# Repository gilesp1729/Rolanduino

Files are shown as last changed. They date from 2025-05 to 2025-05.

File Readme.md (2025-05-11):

# Rolanduino – An Arduino piano/synthesizer

There are quite a few old Roland digital pianos lying around, but parts are impossible to obtain. I had an old HP-237Re whose mechanics were OK but the logic board had died. This project combines the scanning of the keyboard with a synthesizer based on a fork of [Arduino-midi-sound-module](https://github.com/DLehenbauer/arduino-midi-sound-module). I wondered if a Mega2560 could both scan the keyboard and manage the sound production seamlessly…

## Scanning the keyboard

There are many models of these old keyboards but the scanning details are usually quite similar. The schematics of a similar (but not quite the same!) model of Roland are provided here.

The keyboard is wired in groups of 8 keys (11 groups = 88 keys in total) The 8 T-lines are normally high, but each is pulled low in turn to sense each of the 8 notes in each group. Each group has a half-press and full-press line, the timing between them is used to sense key velocity.

In the service manuals they are called SM and PM lines (I don't know what this stands for) but some older keyboards have break and make lines instead.

So there are 11 groups \* 2 bits = 22 bits = 3 bytes reported back from each scan, for a total of 24 bytes from 8 scans.

The PM/SM lines are wired as follows on the Mega to the ports on the heel of the board (the double row connector) while the T lines are connected to port F. There are a lot of wires!

```
  bit     7       6       5       4       3       2       1       0
        -----------------------------------------------------------------
  PORTL |  PM3  |  SM3  |  PM2  |  SM2  |  PM1  |  SM1  |  PM0  |  SM0  |
        -----------------------------------------------------------------
        -----------------------------------------------------------------
  PORTC |  PM7  |  SM7  |  PM6  |  SM6  |  PM5  |  SM5  |  PM4  |  SM4  |
        -----------------------------------------------------------------
        -----------------------------------------------------------------
  PORTA |       |       | PM10  | SM10  |  PM9  |  SM9  |  PM8  |  SM8  |
        -----------------------------------------------------------------
        -----------------------------------------------------------------
  PORTF |  T7   |  T6   |  T5   |  T4   |  T3   |  T2   |  T1   |  T0   |
(output)-----------------------------------------------------------------
```

## Wiring it up

The old logic board is connected to the keyboard by a couple of flat flexible (FFC) cables. These are fragile and unobtainable, as are their sockets. Fortunately the logic board has holes for a couple of different types of keyboards which could be used for 0.1” pitch pins. I sawed the rest of the logic board off to retain the FFC sockets.

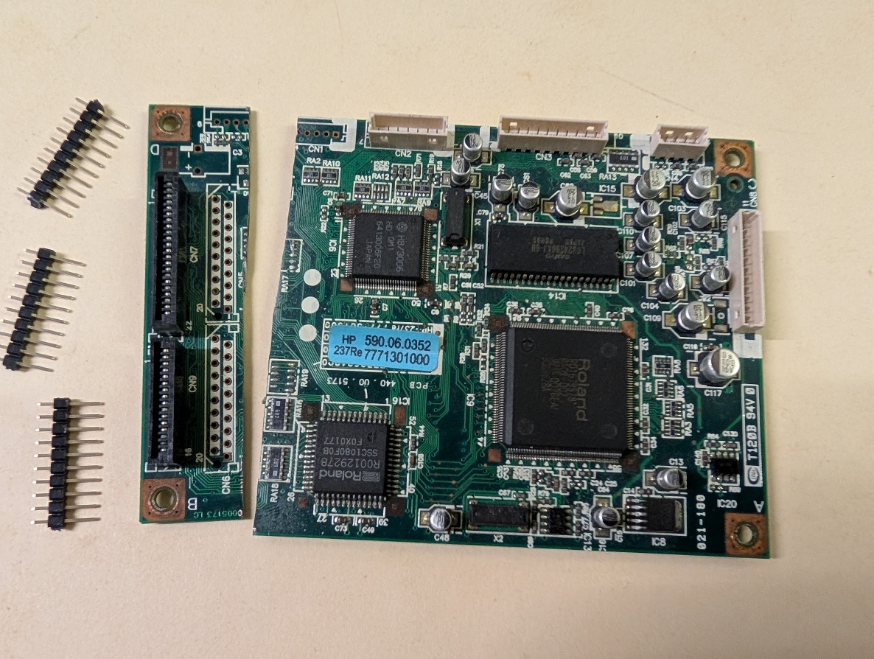
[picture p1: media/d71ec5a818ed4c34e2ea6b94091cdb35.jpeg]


I 3D-printed a carrier to mount the Mega on the original standoffs inside the piano case. The audio output circuit is the same as the one described in Arduino-midi-sound-module, but split into two channels for stereo because the original piano had left and right speakers. Once wired up it looked like this. Did I say a lot of wires?

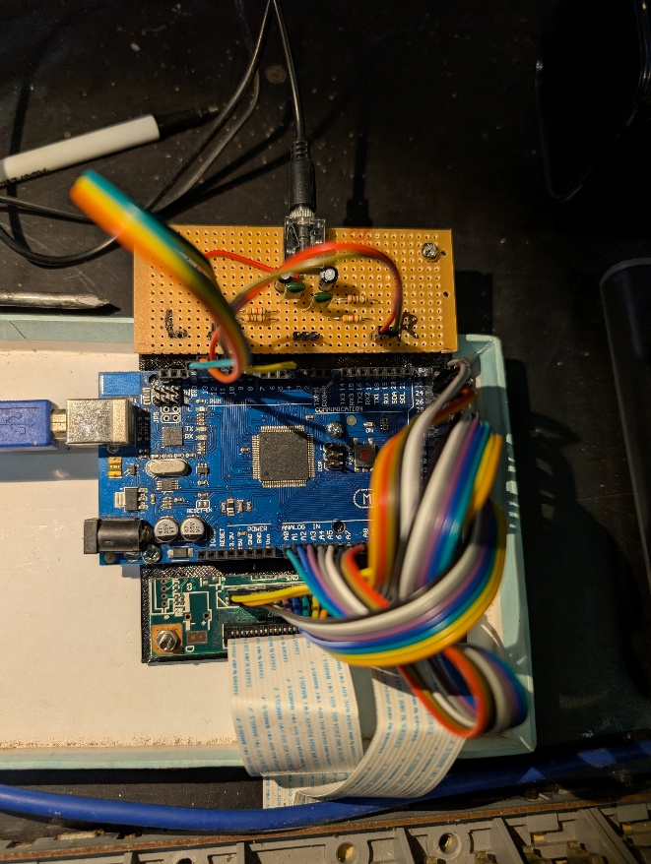
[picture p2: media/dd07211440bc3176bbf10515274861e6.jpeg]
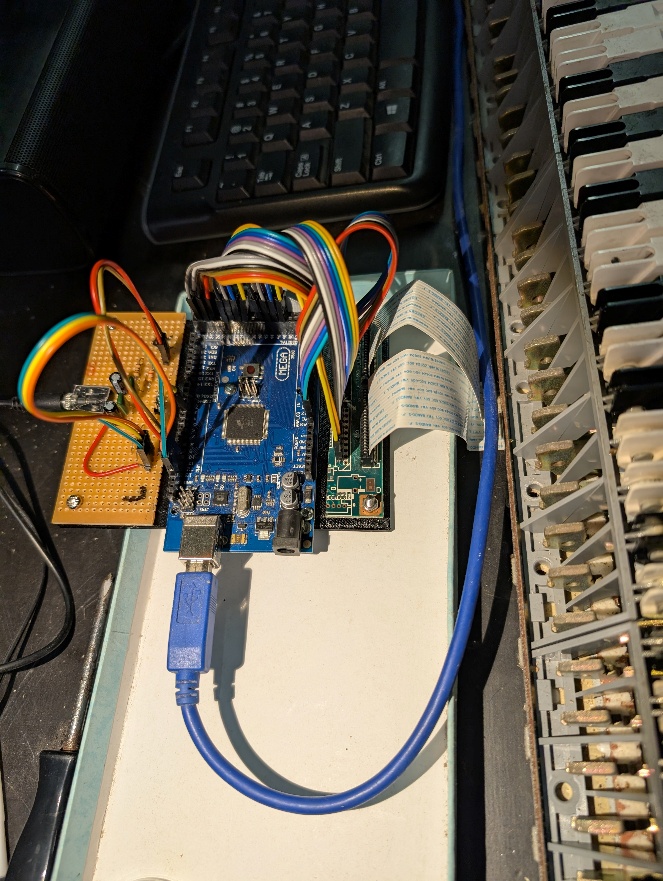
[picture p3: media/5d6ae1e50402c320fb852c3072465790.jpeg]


## The program

My [library fork](https://github.com/gilesp1729/midi-sound-library) is responsible for making waves via PWM. It relies heavily on Timers 0, 1 and 2. The scanning code simply reads ports and gets interrupted a lot, so it needs to be robust against missing key presses. Since there is no UI, instrument selection is via the keyboard by holding down the very bottom note. While holding, playing any other note (white keys only) will select an instrument from the synth's internal table. Not all of them produce unique or correct sounds and have been (or will be) skipped. The percussion have also been skipped for now (only tuned percussion like timpani and xylophones are included)

The instruments are arranged as follows by octave:

```
            -------------------------------------------------------------------------------
 Midi note  | 24       | 36       | 48        | 60       | 72       | 84       | 96       |
 Octave     | C1       | C2       | C3        | C4       | C5       | C6       | C7       |
            | Organs   | Brass    | Woodwinds | Pianos   | Perc.    | Strings  | Effects  |
            -------------------------------------------------------------------------------
 Synth inst     16-23      56-67      68-77      0-15      various      24-46       52-55
   (from instruments_generated.h)
```

The instrument template provided can be stuck on above the keys (it’s sized to suit my keyboard but they are pretty standard). Comments in the code describe the actual instruments used in each section.

When in selection mode, the note you hear will always be in the Middle C octave.

The examples directory also contains a simple test program (scandump) for scanning the keyboard using approximately the same scanning logic.

## Library dependencies

Midi sound library [here](https://github.com/gilesp1729/midi-sound-library).

## Connecting the audio signals

Since Roland pianos vary in their circuit boards there’s no guarantee this will reflect other models. The audio should always be able to be injected at the top of the existing volume control pot.

Here are the Roland’s amp/jack board and power supply/power amp board.

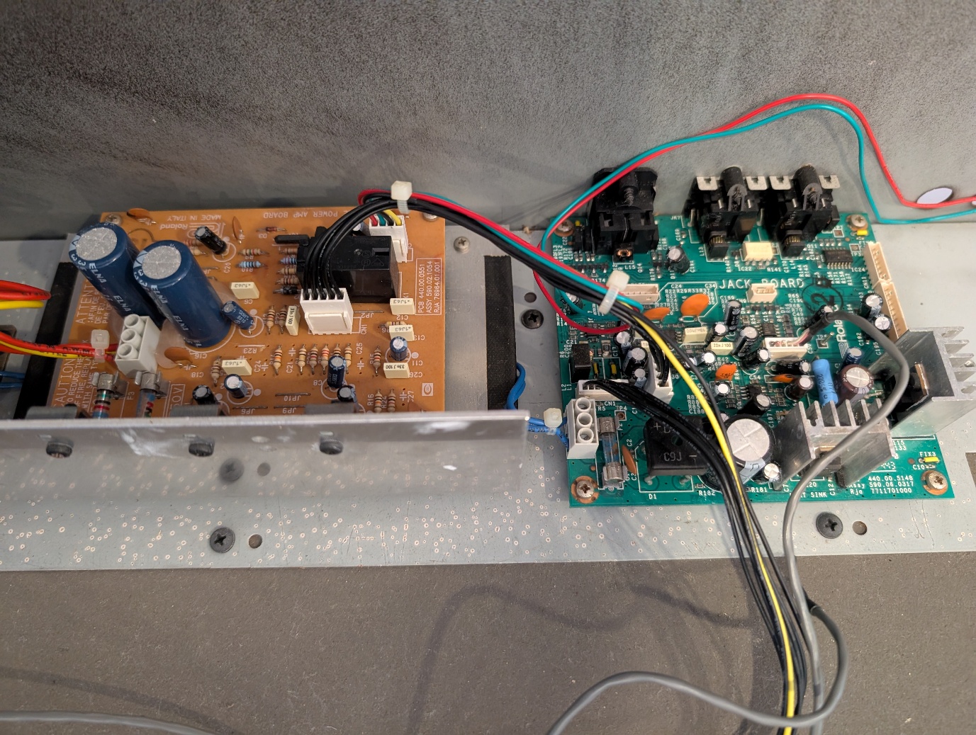
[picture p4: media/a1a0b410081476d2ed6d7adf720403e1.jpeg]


The volume pot connects to this connector on the jack board. Injecting a 1kHz square wave from a scope produced a loud squawk when connected to the top of the pot. Cutting off these wires and connecting to the Mega’s audio circuit completed the audio section.

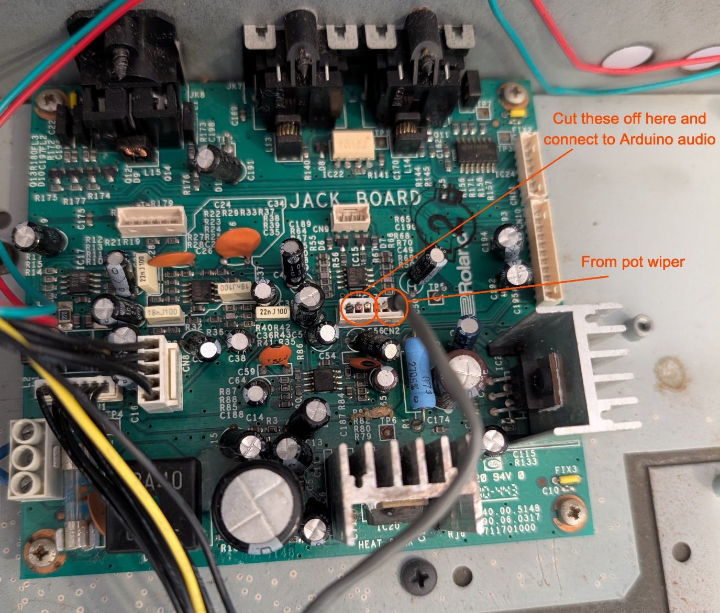
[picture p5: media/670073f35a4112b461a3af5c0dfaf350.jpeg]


There will also likely be a regulated 5V supply somewhere on the Roland’s amp board, but I’m not using that to power the Arduino as it is not recommended to drive the 5V pin directly. To be safe I’ll use a mains powered USB charger connected to the switched mains on the Roland’s power transformer, keeping all the mains stuff covered and out of the way.

## To be continued

Deleting more duplicate and non-working instruments from the selection interface.

Connecting up, and writing code to handle, the three standard piano pedals (soft, sostenuto and sustain)

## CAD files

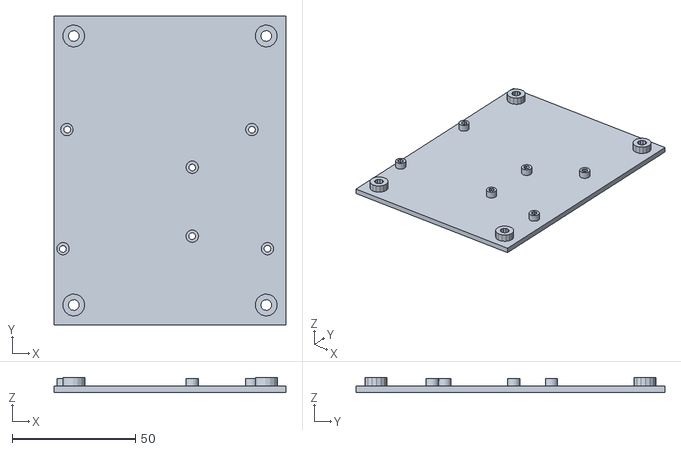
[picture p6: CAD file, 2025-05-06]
3D Prints/scan-carrier.STL
94.0 x 125.0 x 6.00

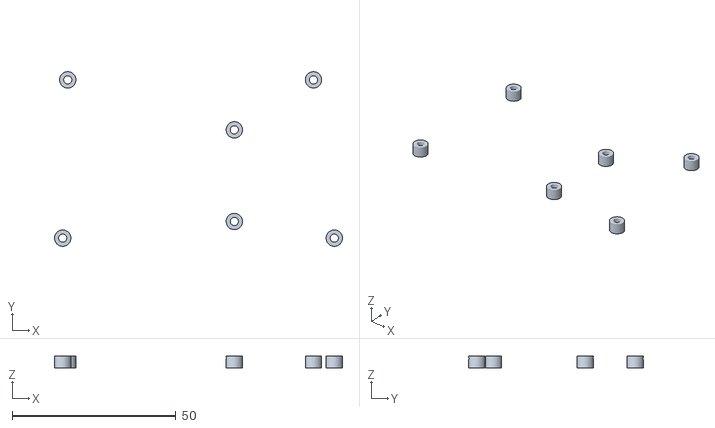
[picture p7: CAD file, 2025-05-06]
3D Prints/mega_standoffs2.STL
87.8 x 53.3 x 3.70

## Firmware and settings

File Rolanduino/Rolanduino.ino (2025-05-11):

// Synthesiser/piano based on an old Roland keyboard and a fork of
// DLehenbauer's excellent synth library. Runs on Arduino Mega2560.
// (the synth will run on Uno as well, but there are not enough pins to scan
// the keyboard)

// Scanning for Roland piano keyboards, such as the HP-237Re. There are many
// models of these old keyboards but the scanning details are usually quite
// similar.

// The keyboard is wired in groups of 8 keys (11 groups = 88 keys in total)
// The 8 T-lines are normally high, but each is pulled low in turn to sense
// each of the 8 notes in each group. Each group has a half-press and full-press
// line, the timing between them is used to sense key velocity.
// In the service manuals they are called SM and PM lines
// (I don't know what this stands for)
// Some older keyboards have break and make lines instead.

// So there are 11 groups * 2 bits = 22 bits = 3 bytes reported
// back from each scan, for a total of 24 bytes from 8 scans.

// The PM/SM lines are wired as follows on the Mega to
// the ports on the heel of the board (the double row connector) while the
// T lines are connected to port F. There are a lot of wires!

//  bit     7       6       5       4       3       2       1       0
//        -----------------------------------------------------------------
//  PORTL |  PM3  |  SM3  |  PM2  |  SM2  |  PM1  |  SM1  |  PM0  |  SM0  |
//        -----------------------------------------------------------------
//        -----------------------------------------------------------------
//  PORTC |  PM7  |  SM7  |  PM6  |  SM6  |  PM5  |  SM5  |  PM4  |  SM4  |
//        -----------------------------------------------------------------
//        -----------------------------------------------------------------
//  PORTA |       |       | PM10  | SM10  |  PM9  |  SM9  |  PM8  |  SM8  |
//        -----------------------------------------------------------------
//        -----------------------------------------------------------------
//  PORTF |  T7   |  T6   |  T5   |  T4   |  T3   |  T2   |  T1   |  T0   |
//(output)-----------------------------------------------------------------


// The default instrument is instrument 0 (grand piano)
// Selection of instruments from the synth is by pressing and holding the
// bottom note on the keyboard for 1 second. While holding, playing any other note
// will select an instrument from the synth's internal table. Not all of them
// produce unique or correct sounds and these have been skipped. The percussion
// have also been skipped for now.

// The instruments are arranged as follows by octave:

//            ----------------------------------------------------------------------------------
// Midi note  | 24       | 36       | 48        | 60       | 72       | 84       | 96      108 |
// Octave     | C1       | C2       | C3        | C4       | C5       | C6       | C7       C8 |
//            | Organs   | Brass    | Woodwinds | Pianos   | Perc.    | Strings  | Effects/vol |
//            ----------------------------------------------------------------------------------
// Synth inst     16-23      56-67      68-77      0-15                  24-46       52-55
//   (from instruments_generated.h)

// When in selection mode, the note you hear will always be in the Middle C octave.
// The last two keys provide an overall volume control.


#include <stdint.h>

// MIDI synth from midi-sound-library
#include "midisynth.h"

MidiSynth synth;


// Key bytes: 2 bits for each key, in key/group order:
// T0 = the low bit pair of all 11 groups
// T1 = the next bit pair of all 11 groups
// and so on. There are two unused bits at the top of each group.
unsigned char keys[24];

// Old key bytes for comparison.
unsigned char last_keys[24];

// Struct for each note on the keyboard.
typedef struct Note
{
  uint32_t  first_tick;   // Tick count (50us) when note first pressed
  bool      playing;      // The note is playing
} Note;

Note notes[88];

// Note offset of bottom note, to make middle C appear as note 60 per Midi
// specs.
int key_offset = 21;

// For instrument selection
static int inst = 0, curr_inst = 0;
static bool new_inst = false;

// Global most recent first_tick to use when a transition to a half-pressed
// key is missed
static uint32_t last_first_tick = 0;

// Timer to detect and enter selection mode
static bool selection_mode = false;
static uint32_t last_note_0_time = 0;

// The selection table is indexed by keyboard note (0-88) and maps
// to a synth instrument number. If an entry is negative, no new selection
// will be made.

// Octaves of the selection table
int selection[88] =
{
  // Unused notes at bottom of keyboard
  -1, -1, -1,

// C       D       E   F       G        A       B
  // C1 octave: Organs
  16, -1, 19, -1, 21, 22, -1, 23, -1, -1, -1, -1,
  //16, 17, 18, 19, 20, 21, 22, 23, -1, -1, -1, -1,

  // C2 octave: Brass
  56, -1, 57, -1, 58, 60, -1, 62, -1, 65, -1, -1,
  //56, 57, 58, 59, 60, 61, 62, 63, 64, 65, 66, 67,

  // C3 octave: Woodwinds
  68, -1, 69, -1, 70, 71, -1, 73, -1, 78, -1, 79,
  //68, 69, 70, 71, 72, 73, 74, 75, 76, 77, -1, -1,

  // C4  and C5 octave: Pianos and related keyoards
   0, -1,  4, -1,  6,  7, -1,  8, -1, -1, -1, -1,

  // C5 octave: Tuned percussion
  47, -1,  9, -1, 11, 12, -1, 13, -1, -1, -1, -1,

  // C6 octave: Strings
  40, -1, 42, -1, 43, 44, -1, 45, -1, 46, -1, -1,

  // C7 octave: Special effects (voice ooh/ahh sounds)
  // and volume control (-2 for down, -3 for up)
  52, -1, 53, -1, 54, 55, -1, -1, -1, -2, -1, -3,

  // That final C8
  -1
};



// Scan the keyboard using 8 T-lines in turn. If the results differ from the
// last scan, return true.
bool scan(void)
{
  bool rc = false;
  int t, i = 0;

  for (t = 0; t < 8; t++)
  {
    PORTF = (unsigned char)(~(1 << t));

    // Delay by ~100us for clock settling in the chip and propagation delay in wiring.
    synth.delayByCount(2);

    keys[i++] = PINL;
    keys[i++] = PINC;
    keys[i++] = PINA;
  }

  // Check for any changes and remember them.
  for (i = 0; i < 24; i++)
  {
    if (keys[i] != last_keys[i])
      rc = true;
  }
  return rc;
}


// Run through the bit pairs of each key and process into a note
// and frequency. Only look for key bit pairs that have changed since
// the last scan.
void process_scan()
{
  for (int t = 0; t < 8; t++)
  {
    // Starting byte in key array of this T-line
    int start_byte = t * 3;

    // For each bit pair (SMx/PMx) within the T-line.
    // i.e. bits (bp, bp+1) of byte (bp / 8).
    for (int bp = 0; bp < 22; bp += 2)
    {
      int byte = start_byte + (bp >> 3);
      int shift = bp & 7;
      int bit_pair = (keys[byte] >> shift) & 0b11;
      int last_bit_pair = (last_keys[byte] >> shift) & 0b11;
      int note = (bp << 2) + t;

      // Check hold-down of bottom note if we want to use it for
      // instrument selection. Note 0 must be held for 1 second.
      if (last_note_0_time != 0 && synth.getDelayCount() - last_note_0_time > 20000)
      {
        if (!selection_mode)
        {
          Serial.println("Selection mode");

          // If Note 0 is playing a continuous note (e.g. an organ)
          // turn it off now, so we can hear the selection notes.
          synth.midiNoteOff(1, key_offset);
        }

        selection_mode = new_inst = true;

        // If in selection mode we are always playing a note from the
        // Middle C octave (note + key_offset = 60-71) and which
        // instrument is selected depends on the note played.
        // Note 0 must not be modified (it's tested for later)
        if (note > 0)
        {
          int key = (note + key_offset) % 12;
          int middle_c = 60 - key_offset;

          // Look up the instrument from the table. An entry of -1
          // will not play or select anything. An entry of -2 or -3
          // controls the volume.
          if (selection[note] < 0)
            continue;
          inst = selection[note];

          // Modify the note to be in the Middle C octave. Remember this
          // modified note so we can turn it off later (in case note 0 is
          // released first)
          note = middle_c + key;
        }
      }

      // If no change in the keys, then there is nothing more to do
      if (bit_pair == last_bit_pair)
        continue;

      // A key has been pressed and the PM line is low.
      // Remember the tick count both per note and globally.
      // We have to handle repeated 01 -> 00 transitions
      // without going back to 11 (key fully released)
      if (bit_pair == 0b01)
        notes[note].first_tick = last_first_tick = synth.getDelayCount();

      // The key has gone all the way down.
      // This is where the note will be started.
      // In practice the travel times are from ~40-150ms
      // or 800-3000 ticks.

      // If somehow we have missed the PM line going down
      // (i.e straight from 11 to 00) then the first_tick
      // will be invalid and the last_first_tick is used instead.

      // The midi note is (note + key_offset) .

      if (bit_pair == 0b00)
      {
        uint32_t ticks;
        int vel;

        // But first, see if we have had a change of instrument,
        // or we are in selection mode
        if (new_inst && inst != curr_inst)
        {
          char name[80];

          Instruments::getInstrumentName(inst, name);
          Serial.print(inst);
          Serial.print(": ");
          Serial.println(name);
          synth.midiProgramChange(1, inst);
          curr_inst = inst;
          inst = 0;     // ready for next instrument change
          new_inst = false;
        }

        //Serial.print("Note ");
        //Serial.println(note + key_offset);

        // Time the transition from 01 to 00. If the 11-01 transition
        // was missed, use the last_first_tick as a backup.
        if (notes[note].first_tick != 0)
        {
          ticks = synth.getDelayCount() - notes[note].first_tick;
          //Serial.print("Ticks ");
        }
        else
        {
          ticks = synth.getDelayCount() - last_first_tick;
          //Serial.print("Ticks* ");
        }

        notes[note].playing = true;
        vel = 178 - (ticks >> 4);   // approximate mapping to 16-127
        if (vel < 16)
          vel = 16;
         else if (vel > 127)
          vel = 127;

        //Serial.print(ticks);
        //Serial.print(" vel ");
        //Serial.println(vel);
        synth.midiNoteOn(1, note + key_offset, (uint8_t)vel);

        // If Note 0 is currently playing, remember the first time it
        // was pressed (in case we are going into selection mode)
        if (!selection_mode && note == 0)
          last_note_0_time = synth.getDelayCount();
      }

      // The note has been released. Clear its first_tick counter.
      if (bit_pair == 0b11 && last_bit_pair != 0b11 && notes[note].playing)
      {
        notes[note].first_tick = 0;
        notes[note].playing = false;
        //Serial.print("Note released ");
        //Serial.println(note + key_offset);
        synth.midiNoteOff(1, note + key_offset);

        // Note 0 has been released; turn off selection mode and all notes.
        if (note == 0)
        {
          last_note_0_time = 0;
          selection_mode = new_inst = false;
          synth.midiControlChange(1, 0x7B, 0);    // all notes off
          curr_inst = inst;
          inst = 0;
          Serial.println("Selection mode exited");
        }
      }
    }
  }

  // Update last_keys array now that we have processed the changes
  for (int i = 0; i < 24; i++)
    last_keys[i] = keys[i];
}

void setup(void)
{
  // We are dumping, so set the serial port up. Comment out when running from
  //external power without the serial monitor.
  //Serial.begin(9600);
  //while (!Serial)
  //  ;

  // Use DDR register to set all bits of the port to OUTPUT.
  DDRF = 0xFF;    // set port F to all output

  // Set all bits of the ports to INPUT_PULLUP.
  PORTL = 0xFF;
  PORTC = 0xFF;
  PORTA = 0xFF;

  // Set up notes
  for (int i = 0; i < 88; i++)
  {
    notes[i].first_tick = 0;
    notes[i].playing = false;
  }

  // Set up last_keys so we don't get spurious releases at the start
  for (int i = 0; i < 24; i++)
    last_keys[i] = 0xFF;

  synth.begin();                          // Start synth sample/mixing on Timer2 ISR
  sei();                                  // Begin processing interrupts.
}

void loop(void)
{
  // Scan the keyboard and process any new notes.
  if (scan())
    process_scan();

  // Look on the serial monitor for changes of instrument.
  // Accept a 2 or 3 digit number here by building up digits.
  if (Serial.available())
  {
    int key = Serial.read();
    if (key >= '0' && key <= '9')
    {
      inst = (inst * 10) + (key - '0');
      new_inst = true;
    }
  }
}

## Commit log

2025-05-06 Initial commit.
    [mega_standoffs2.STL, scan-carrier.STL]
2025-05-08 Update instrument selection by keyboard (white keys only). Add key map to print and stick on.
    [Roland237Re-PinMap.xlsx]
2025-05-11 Fix timing bug where note was left playing in selection mode.
    [Rolanduino.ino]
